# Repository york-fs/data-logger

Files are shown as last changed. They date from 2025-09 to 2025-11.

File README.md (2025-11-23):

# Data Logging Board







This is a custom PCB data-logger designed to work on our Formula Student car. It captures data from the vehicle's CAN bus, transmits telemetry, and logs to an SD card. Additionally, the data logger stores configuration information on EEPROM. 

## Key Features
- **CAN bus interface** for vehicle data logging  
- **SD card slot** for onboard storage
- **EEPROM** for storing config data
- **Real-time clock (RTC)** with battery backup for accurate timestamps  
- **USB interface** for configuration and file transfer  
- **UART output** to a SiK telemetry radio for live data streaming  
- **Status LEDs** for logging, USB power, and telemetry status

## PCB Notes
- Designed in KiCad 9.0
- 3D models stored in external library (lib)

data_logger

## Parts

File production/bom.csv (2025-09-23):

Designator | Footprint | Quantity | Value | LCSC Part #
BAT2 | BAT-SMD_BS-CR2032-8 | 1 | BS-CR2032-8 | C7498149
C1 | CP_Elec_6.3x5.4 | 1 | 10u
C10, C11, C12, C13, C14, C19, C2, C20, C21, C3, C4 | 0603 | 11 | 1u
C15, C9 | 0603 | 2 | 100n
C17, C18 | 0603 | 2 | 100p
C5, C6 | 0603 | 2 | 30p
C7, C8 | 0603 | 2 | 20p
D1, D4 | D_SOD-123F | 2 | 1N4007
D2, D5 | D_SMA | 2 | SS34
D3, D6, D7, D9 | 0603 | 4 | LED_Small
D8 | SOT-23 | 1 | PESD2CAN
F1 | 0805 | 1 | Polyfuse
H1, H2, H3, H4 | MountingHole_3.2mm_M3_Pad_Via | 4 | MountingHole_Pad
J1 | 10067847-001RLF_AMP | 1 | 10067847-001RLF
J2 | USB_C_Receptacle_G-Switch_GT-USB-7010ASV | 1 | USB_C_Receptacle_USB2.0_14P
J3 | JST_PH_B6B-PH-K_1x06_P2.00mm_Vertical | 1 | SiK Radio Module
J4 | PinHeader_1x06_P2.54mm_Vertical | 1 | SWD
J5 | 776280-1 | 1 | 776280-1
J7 | TerminalBlock_bornier-2_P5.08mm | 1 | CAN Terminal
R1, R8 | 0603 | 2 | 10k
R10, R9 | 0603 | 2 | 5k1
R11, R14, R15 | 0603 | 3 | 330
R12 | 0603 | 1 | 120
R13 | 0603 | 1 | 100k
R2 | 0603 | 1 | 1K5
R3, R4, R5, R6, R7 | 0603 | 5 | 33
SW1 | SW_Push_SPST_NO_Alps_SKRK | 1 | SW_Push
TP1, TP2, TP3, TP4, TP5 | TestPoint_Keystone_5000-5004_Miniature | 5 | TestPoint
U1 | SOT-89-3 | 1 | MCP1700x-330xxMB
U2 | TO-252-2 | 1 | TPS7B88-Q1
U3 | LQFP-48_7x7mm_P0.5mm | 1 | STM32F103C8Tx
U4 | SOT-23-6 | 1 | USBLC6-2SC6
U5 | SOIC-8_3.9x4.9mm_P1.27mm | 1 | SN65HVD1050D
U6 | SOIC-8_3.9x4.9mm_P1.27mm | 1 | M24C64-R
Y1 | Crystal_SMD_5032-2Pin_5.0x3.2mm | 1 | 8M
Y2 | Crystal_SMD_G8-2Pin_3.2x1.5mm | 1 | 32.768k

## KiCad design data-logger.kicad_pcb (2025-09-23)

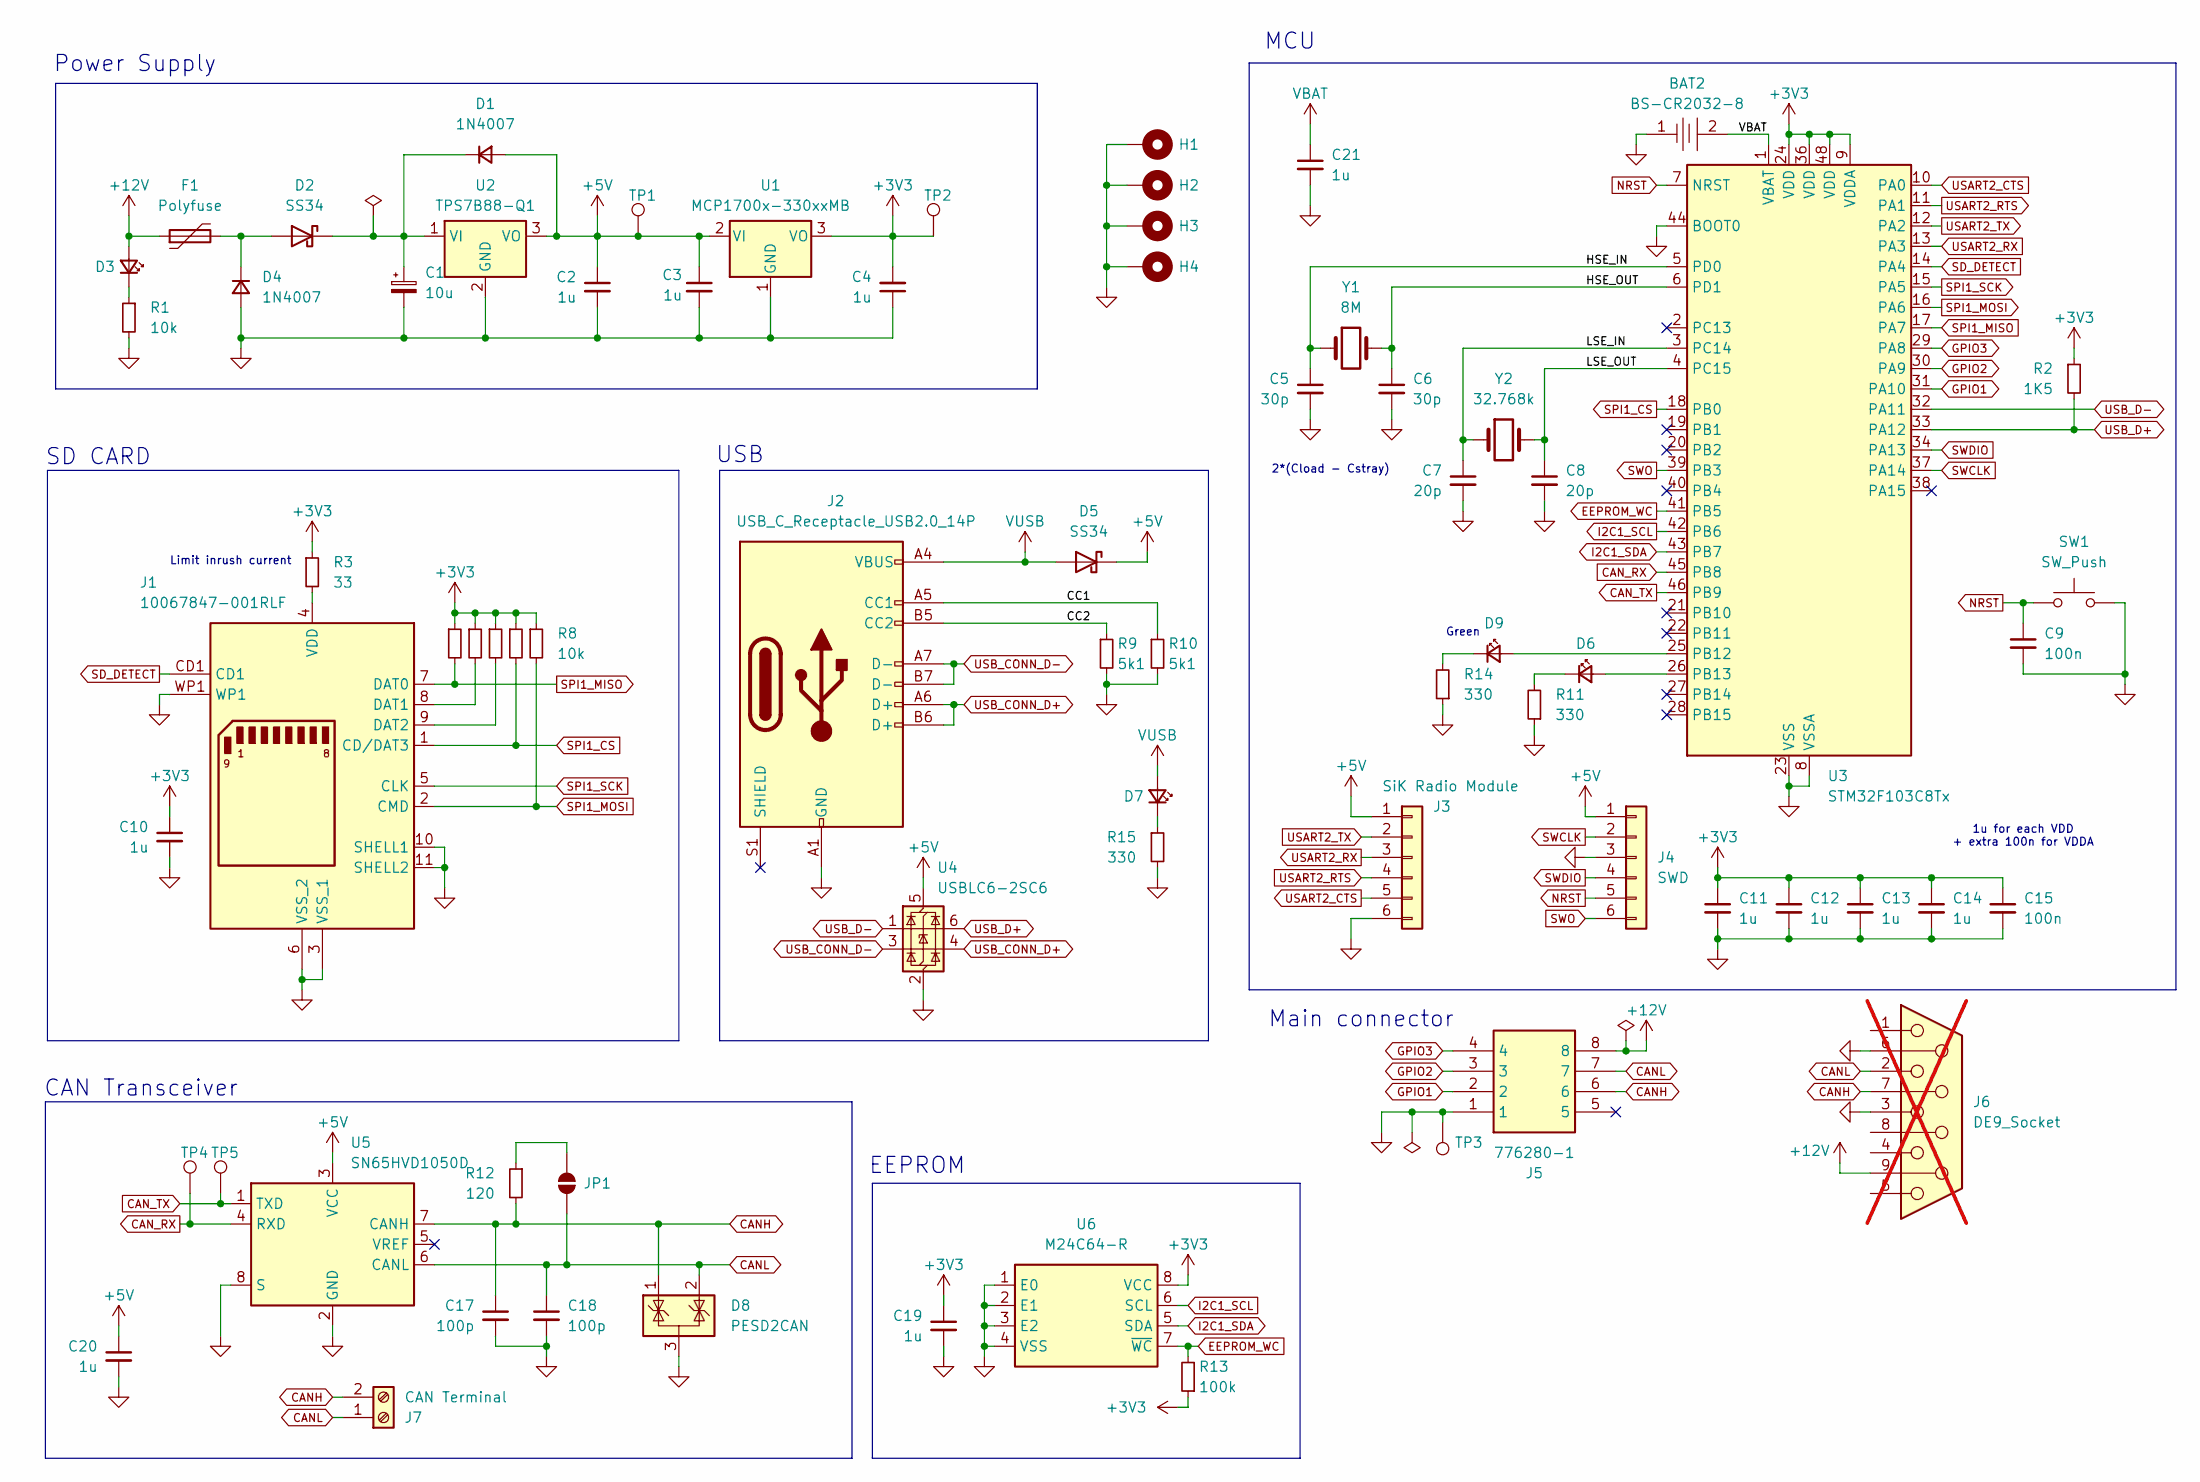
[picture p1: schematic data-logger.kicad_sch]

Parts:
BAT2: BS-CR2032-8; BAT-SMD_BS-CR2032-8; LCSC Part C7498149
C1: 10u; CP_Elec_6.3x5.4
C2, C3, C4, C10, C11, C12, C13, C14, C19, C20, C21: 1u; C_0603_1608Metric
C5, C6: 30p; C_0603_1608Metric
C7, C8: 20p; C_0603_1608Metric
C9, C15: 100n; C_0603_1608Metric
C17, C18: 100p; C_0603_1608Metric
D1, D4: 1N4007; D_SOD-123F
D2, D5: SS34; D_SMA
D3, D6, D7, D9: LED_Small; LED_0603_1608Metric
D8: PESD2CAN; SOT-23
F1: Polyfuse; R_0805_2012Metric
H1, H2, H3, H4: MountingHole_Pad; MountingHole_3.2mm_M3_Pad_Via
J1: 10067847-001RLF; 10067847-001RLF_AMP; Mouser Part Number 649-10067847-001RLF
J2: USB_C_Receptacle_USB2.0_14P; USB_C_Receptacle_G-Switch_GT-USB-7010ASV
J3: SiK Radio Module; JST_PH_B6B-PH-K_1x06_P2.00mm_Vertical
J4: SWD; PinHeader_1x06_P2.54mm_Vertical
J5: 776280-1; Mouser Part Number 571-776280-1
J6: DE9_Socket; not fitted
J7: CAN Terminal; TerminalBlock_bornier-2_P5.08mm
JP1: SolderJumper_2_Open; SolderJumper-2_P1.3mm_Open_RoundedPad1.0x1.5mm
R1, R8: 10k; R_0603_1608Metric
R2: 1K5; R_0603_1608Metric
R3, R4, R5, R6, R7: 33; R_0603_1608Metric
R9, R10: 5k1; R_0603_1608Metric
R11, R14, R15: 330; R_0603_1608Metric
R12: 120; R_0603_1608Metric
R13: 100k; R_0603_1608Metric
SW1: SW_Push; SW_Push_SPST_NO_Alps_SKRK
TP1, TP2, TP3, TP4, TP5: TestPoint; TestPoint_Keystone_5000-5004_Miniature
U1: MCP1700x-330xxMB; SOT-89-3
U2: TPS7B88-Q1; TO-252-2
U3: STM32F103C8Tx; LQFP-48_7x7mm_P0.5mm
U4: USBLC6-2SC6; SOT-23-6
U5: SN65HVD1050D; SOIC-8_3.9x4.9mm_P1.27mm
U6: M24C64-R; SOIC-8_3.9x4.9mm_P1.27mm
Y1: 8M; Crystal_SMD_5032-2Pin_5.0x3.2mm
Y2: 32.768k; Crystal_SMD_G8-2Pin_3.2x1.5mm

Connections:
+3V3: C4.2, C10.1, C11.1, C12.1, C13.1, C14.1, C15.1, C19.1, R2.1, R3.1, R4.1, R5.1, R6.1, R7.1, R8.1, R13.1, TP2.1, U1.3 (VO), U3.9 (VDDA), U3.24 (VDD), U3.36 (VDD), U3.48 (VDD), U6.8 (VCC)
+5V: C2.1, C3.1, C20.1, D1.2 (A), D5.1 (K), J3.1, J4.1, TP1.1, U1.2 (VI), U2.3 (VO), U4.5 (VBUS), U5.3 (VCC)
+12V: D3.2 (A), F1.1, J5.8, J6.9
/CC1: J2.A5 (CC1), R10.1
/CC2: J2.B5 (CC2), R9.1
/HSE_IN: C5.1, U3.5 (PD0), Y1.1
/HSE_OUT: C6.1, U3.6 (PD1), Y1.2
/LSE_IN: C7.1, U3.3 (PC14), Y2.1
/LSE_OUT: C8.1, U3.4 (PC15), Y2.2
CANH: C17.1, D8.1 (K), J5.6, J6.7, J7.2, R12.2, U5.7 (CANH)
CANL: C18.1, D8.2 (K), J5.7, J6.2, J7.1, JP1.2 (B), U5.6 (CANL)
CAN_RX: TP4.1, U3.45 (PB8), U5.4 (RXD)
CAN_TX: TP5.1, U3.46 (PB9), U5.1 (TXD)
EEPROM_WC: R13.2, U3.41 (PB5), U6.7 (~WC)
GND: BAT2.1, C1.2, C2.2, C3.2, C4.1, C5.2, C6.2, C7.2, C8.2, C9.2, C10.2, C11.2, C12.2, C13.2, C14.2, C15.2, C17.2, C18.2, C19.2, C20.2, C21.2, D4.2 (A), D8.3 (A), H1.1, H2.1, H3.1, H4.1, J1.3 (VSS_1), J1.6 (VSS_2), J1.10 (SHELL1), J1.11 (SHELL2), J1.WP1, J2.A1 (GND), J2.A12 (GND), J2.B1 (GND), J2.B12 (GND), J3.6, J4.3, J5.1, J6.3, J6.6, R1.2, R9.2, R10.2, R11.1, R14.1, R15.2, SW1.2, TP3.1, U1.1 (GND), U2.2 (GND), U3.8 (VSSA), U3.23 (VSS), U3.35 (VSS), U3.44 (BOOT0), U3.47 (VSS), U4.2 (GND), U5.2 (GND), U5.8 (S), U6.1 (E0), U6.2 (E1), U6.3 (E2), U6.4 (VSS)
GPIO1: J5.2, U3.31 (PA10)
GPIO2: J5.3, U3.30 (PA9)
GPIO3: J5.4, U3.29 (PA8)
I2C1_SCL: U3.42 (PB6), U6.6 (SCL)
I2C1_SDA: U3.43 (PB7), U6.5 (SDA)
NRST: C9.1, J4.5, SW1.1, U3.7 (NRST)
unnamed: C1.1, D1.1 (K), D2.1 (K), U2.1 (VI)
unnamed: D2.2 (A), D4.1 (K), F1.2
unnamed: D3.1 (K), R1.1
unnamed: D6.2 (A), U3.26 (PB13)
unnamed: D6.1 (K), R11.2
unnamed: D7.1 (K), R15.1
unnamed: D9.2 (A), U3.25 (PB12)
unnamed: D9.1 (K), R14.2
unnamed: J1.8 (DAT1), R5.2
unnamed: J1.9 (DAT2), R6.2
unnamed: J1.4 (VDD), R3.2
unnamed: JP1.1 (A), R12.1
SD_DETECT: J1.CD1, U3.14 (PA4)
SPI1_CS: J1.1 (CD/DAT3), R7.2, U3.18 (PB0)
SPI1_MISO: J1.7 (DAT0), R4.2, U3.17 (PA7)
SPI1_MOSI: J1.2 (CMD), R8.2, U3.16 (PA6)
SPI1_SCK: J1.5 (CLK), U3.15 (PA5)
SWCLK: J4.2, U3.37 (PA14)
SWDIO: J4.4, U3.34 (PA13)
SWO: J4.6, U3.39 (PB3)
USART2_CTS: J3.5, U3.10 (PA0)
USART2_RTS: J3.4, U3.11 (PA1)
USART2_RX: J3.3, U3.13 (PA3)
USART2_TX: J3.2, U3.12 (PA2)
USB_CONN_D+: J2.A6 (D+), J2.B6 (D+), U4.4 (I/O2)
USB_CONN_D-: J2.A7 (D-), J2.B7 (D-), U4.3 (I/O2)
USB_D+: R2.2, U3.33 (PA12), U4.6 (I/O1)
USB_D-: U3.32 (PA11), U4.1 (I/O1)
VBAT: BAT2.2, C21.1, U3.1 (VBAT)
VUSB: D5.2 (A), D7.2 (A), J2.A4 (VBUS), J2.A9 (VBUS), J2.B4 (VBUS), J2.B9 (VBUS)

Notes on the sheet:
SD CARD
Main connector
1u for each VDD + extra 100n for VDDA
CAN Transceiver
2*(Cload - Cstray)
MCU
USB
EEPROM
Limit inrush current
Green
Power Supply

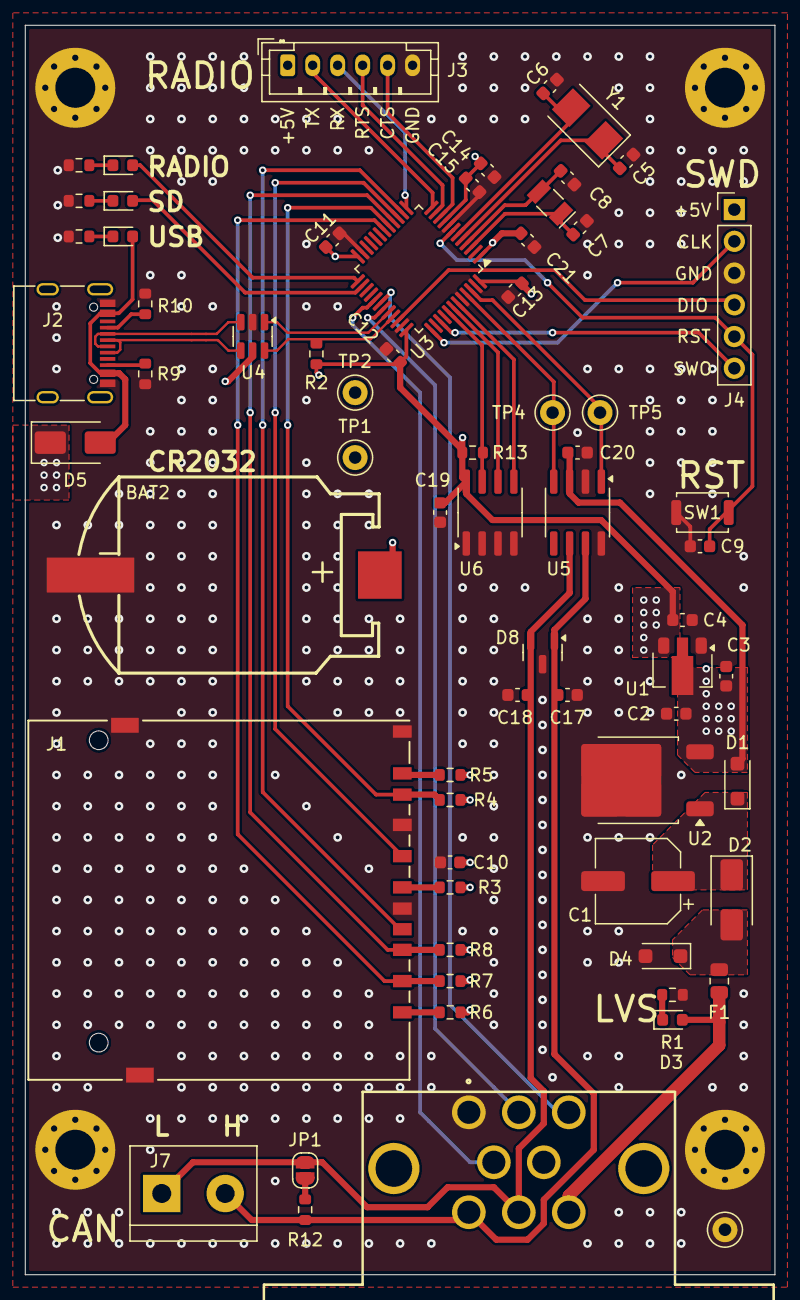
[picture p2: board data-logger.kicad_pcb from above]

Board: 4 copper layers, 60.0 x 100.0 mm, 71 parts (0 on the bottom side), 51 nets.

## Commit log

2025-09-23 Revision A
    [data-logger.kicad_pcb, data-logger.kicad_sch, hall.kicad_sch]
2025-09-23 Rev A production files
    [bom.csv, designators.csv, positions.csv]
2025-10-22 kicad-library: Add submodule
2025-11-23 ci: Update to latest kicad workflow
